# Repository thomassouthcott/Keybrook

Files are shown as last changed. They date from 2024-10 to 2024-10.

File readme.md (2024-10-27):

# Keybrook
> Most of the keys are gone!? The hitbox for keyboard warriors.

Product Image
<p>A hitbox in the form factor of a 60% keyboard. Compatible with the Brook P3/P4 Mini and Brook P5 Mini. Small form factor, USB-C and fits with 60% keyboard carry cases for easy transport. Change the keycaps and cases to further customise your hitbox.</p>

| Renders |
| :-----------:|
| PCB |
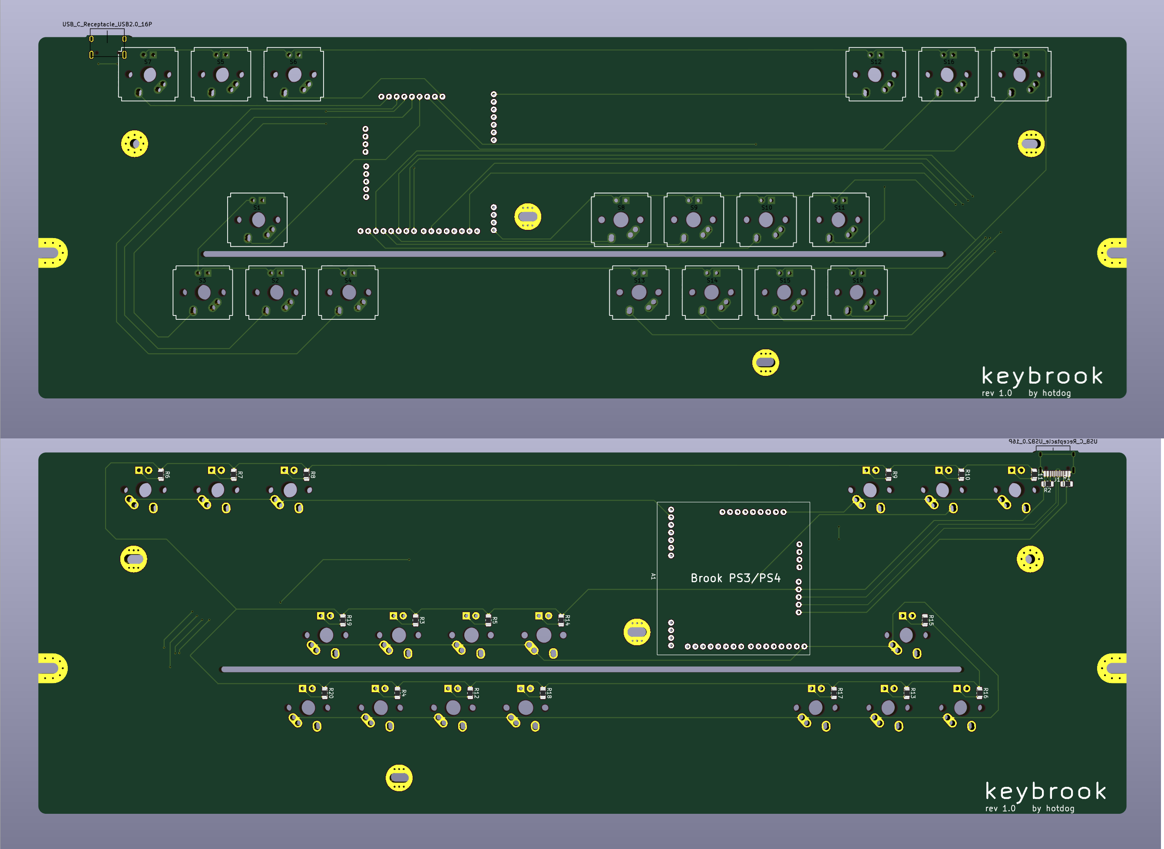
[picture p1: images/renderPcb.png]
PCB Render
|  |
| 3D Printed Faceplate |
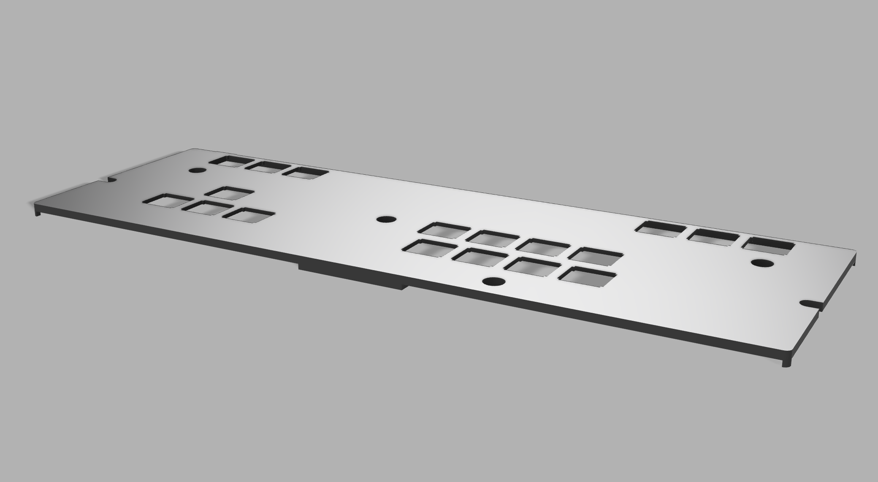
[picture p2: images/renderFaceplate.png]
Faceplate Render
|  |
## Parts List
- Brook P3/P4 Mini or Brook P5 Mini
- Resin 3D Printed Faceplate
- 18 1.8mm White LEDs
- 18 Key Switches
- GH60 Compatible PC Case (Modifications might be needed)
- 40 Break Away 2.0mm Pitch Board to Board Pins
- Keycaps for F1 - F6 or F1 - F3, F10 - F12
- Keycaps for WASD
- Keycaps for JUIKOLP;

Parts Required
## Assembly
### _Step 1 (Optional)
Apply vinyl wrap to the faceplate.
### _Step 2_
Modify case to allow the PCB to sit flush.

### _Step 3_
Solder the board to board pins into the backside of the PCB.

### _Step 4_
Solder the LEDs into the frontside of the PCB, the circular pads are positive.

### _Step 5_
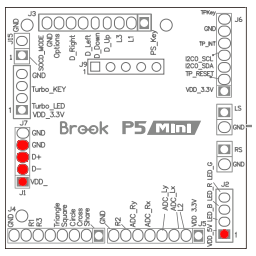
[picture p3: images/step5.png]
Step 5 Image
Put on Brook P5 Mini and solder LED pins and USB pins. <details ><summary>See Image</summary></details>

### _Step 6_ 
Plug it in to check all LEDS work. 

### _Step 7_
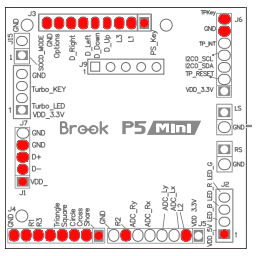
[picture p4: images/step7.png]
Step 7 Image
Solder the following pins.<details ><summary>See Image </summary></details>

### _Step 8_
With the faceplate in place; solder F1, F6, A, ; switches.

### _Step 9_ 
Solder rest of keyswitches.

### _Step 10_ 
Put the case and keycaps on.

> **Done!**  
## Special Thanks
- [ai03-2725 / Voyager60](https://github.com/ai03-2725/Voyager60)
- [Breadcrumbsflatbox / hardware-rev3](https://github.com/jfedor2/flatbox/tree/master/hardware-rev3)

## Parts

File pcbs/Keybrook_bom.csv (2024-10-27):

Id | Designator | Footprint | Quantity | Designation | Supplier and ref
2 | REF** | 60_Outline-Modded | 1 | 60_Outline
3 | S16,S13,S18,S10,S17,S8,S9,S3,S14,S15,S1,S6,S5,S4,S11,S2,S12,S7 | MX-1U-FLIPPED | 18 | Keyswitch
4 | R19,R8,R5,R11,R10,R6,R15,R4,R14,R18,R3,R13,R7,R9,R20,R12,R16,R17 | R_0805_2012Metric_Pad1.20x1.40mm_HandSolder | 18 | 120 Ohm
5 | R2,R1 | R_0805_2012Metric_Pad1.20x1.40mm_HandSolder | 2 | 5.1k
6 | J1 | HRO-TYPE-C-31-M-12 | 1 | USB_C_Receptacle_USB2.0_16P

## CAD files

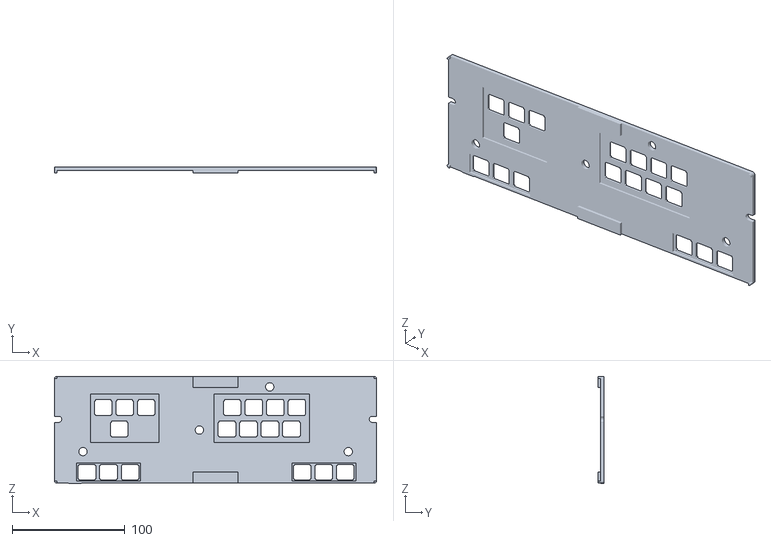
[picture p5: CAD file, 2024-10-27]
3d printed faceplate/Keybrook_faceplate.stl
285.0 x 5.00 x 95.1
